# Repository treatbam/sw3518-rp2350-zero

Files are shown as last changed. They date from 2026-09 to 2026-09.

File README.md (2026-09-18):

# sw3518-rp2350-zero

Portable **SW3518** USB charger meter on **Waveshare RP2350-Zero** with a **1.4″ SPI TFT (128×128 ST7735S)**, two momentary buttons, and a small haptic motor.

This is the pocket / field sibling of [sw3518-GEEK](https://github.com/treatbam/sw3518-GEEK). **`env:rp2350-zero` has no Wi‑Fi.** **`env:picow`** (this `picow` branch) is the same TFT meter on a **Raspberry Pi Pico W** with **MQTT Home Assistant discovery**.

MIT licensed.

## Features (MVP)

| Page | Contents |
|---|---|
| **MAIN** | Large total W (text size 3), tight Vin/Vout + C/A row, load-share, compact C/A sparklines |
| **C** | USB-C zoom (large W, V/A, peaks, ~42px sparkline) |
| **A** | USB-A zoom |
| **S** | Compact PEAK/AVG/ENERGY grid, then C/A spark bands |

- Status crumbs along the top (`M C A S`) + live/idle pip (short labels so nothing overflows 128px)
- Square **128×128** layouts packed for the 1.4″ panel; ASCII-only TFT strings
- Session tracking in RAM (charged ms while load present, mWh, peaks) — no NVS required for MVP. I2C loss **pauses** energy (does not bill the outage). Host tests: `make -C tests test`.
- Haptic pulse on protocol change, page enter, session clear, and A-long test
- Night dim: backlight PWM drops after ~90 s idle; any button wakes it
- Onboard **WS2812** (GP16): blink *count* = what’s missing. 0 = OK (dim cyan heartbeat), **1 orange = SW3518 missing**, 2 magenta = TFT missing, 3 red = both. Night dim lowers brightness. TFT has no MISO on this pin map, so 2-blink cannot be proven and is reserved.

### Button grammar

| Button | Short | Long (~800 ms) |
|---|---|---|
| **A** (GP6) | Next page | Haptic test pulse |
| **B** (GP7) | Jump to Session (or prev if already there) | Clear session + haptic |

Optional third **Mode** button is reserved in comments in `include/pins.h` (unused in MVP).

## Default pin map

Soldering helper (Zero front/back + wire-to-part): [`docs/wiring-solder-guide.png`](docs/wiring-solder-guide.png). Regenerate with `python3 docs/make_solder_pinout.py`.

Edit `include/pins.h` (also summarized here).

| Function | GPIO | Notes |
|---|---|---|
| TFT SCK | **2** | SPI0 SCK, **front** edge |
| TFT MOSI | **3** | SPI0 TX, front edge |
| TFT CS | **1** | front edge |
| TFT DC | **15** | front left (GP16 is onboard WS2812) |
| TFT RST | **8** | front edge |
| TFT BL | **14** | PWM night dim, front left |
| WS2812 | **16** | Onboard RGB (Waveshare schematic DIN, `PICO_DEFAULT_WS2812_PIN`) |
| I2C SDA | **4** | Wire / **I2C0** (RP2350 GP4/5) |
| I2C SCL | **5** | SW3518 addr **0x3C** |
| BTN_A | **6** | `INPUT_PULLUP`, active LOW |
| BTN_B | **7** | `INPUT_PULLUP`, active LOW |
| HAPTIC | **9** | Active HIGH → N‑FET gate |

> **I2C naming:** GP4/GP5 are **I2C0** (`Wire`) on RP2350. The “I2C1” label in planning docs meant “the charger I2C bus,” not the hardware I2C1 block (that would be GP6/7 and would collide with the buttons).

## Pico W (`env:picow`)

Same 128×128 UI and SW3518 I2C driver. Wi-Fi publishes GEEK-style **MQTT sensors** with Home Assistant discovery (`homeassistant/sensor/sw3518pw_xxxx/...`). ESPHome would mean rewriting the charger + TFT stack; MQTT on this firmware is the smaller path.

Solder helper: [`docs/wiring-solder-guide-picow.png`](docs/wiring-solder-guide-picow.png) (`python3 docs/make_solder_pinout_picow.py`).

| Function | Pico W GPIO | Notes |
|---|---|---|
| TFT SCK | **18** | SPI0, right rail |
| TFT MOSI | **19** | SPI0 |
| TFT CS | **17** | |
| TFT DC | **none** | 3-wire SPI (`PIN_TFT_DC = -1`). If the FPC says **A0** or **RS**, that is DC — wire it to GP16. |
| TFT RST | **20** | |
| TFT BL | **21** | PWM |
| I2C SDA/SCL | **4 / 5** | SW3518 `0x3C` |
| BTN A/B | **6 / 7** | same grammar |
| Haptic | **9** | |
| Status | **LED_BUILTIN** | CYW43 LED, blink count = SW3518 missing |

```bash
cp include/secrets.h.example include/secrets.h   # fill WIFI_SSID, MQTT_HOST, …
pio run -e picow
```

Empty `WIFI_SSID` still builds (TFT-only). Topics: `picow/sw3518/{vin,vout,i_c,i_a,power,power_c,power_a,protocol,session_wh,session_peak_w,charging,linked,status}`. Do not use GP23–25 (Wi-Fi). Pico BOOT/RUN are flash/reset, not UI.

**ESPHome rewrite** (native HA API, OTA, YAML TFT): `sw3518-picow.yaml` + `components/sw3518/` at the **repo root**. Copy `secrets.yaml.example` → `secrets.yaml`, then `esphome run sw3518-picow.yaml`. Same Pico W pins. Arduino `env:picow` MQTT and ESPHome are alternatives — flash one or the other.

## Display / ST7735 init

Assumes a **1.4″ / 1.44″ 128×128** ST7735S module driven by **Adafruit_ST7735**.

Default init tab (sets 128 height + column/row start — do **not** use the 1.8″ BLACKTAB/GREENTAB here):

```cpp
#define ST7735_INIT_TAB INITR_144GREENTAB
```

If the image is shifted a few pixels, try `INITR_HALLOWING` (also 128×128) in `include/pins.h`. Flip rotation with `1`/`2`/`3` in `initDisplay()` if the panel is mounted rotated.

A full RGB565 canvas (`128×128×2 = 32 KB`) is used; RP2350 SRAM (~520 KB) is fine.

## BOM notes

- **Waveshare RP2350-Zero**
- **SW3518 / SW3518S** charger module with I2C (0x3C)
- **1.4″ SPI ST7735S** 128×128 TFT
- **2×** momentary NO buttons to GND
- **Haptic / coin vibration motor** driven by an **N‑channel MOSFET** (logic-level gate from GP9), **flyback diode** across the motor, motor supply from 3V3 or 5V as appropriate for the motor (do **not** power the motor through the GPIO)

```
GP9 ──[series R ~100Ω optional]── FET gate
FET source ── GND
FET drain ── motor (−)
motor (+) ── 3V3/5V
diode cathode to motor (+), anode to drain
```

## PlatformIO

Uses **earlephilhower Arduino-Pico** via maxgerhardt’s PlatformIO platform:

```ini
[env:rp2350-zero]
platform = https://github.com/maxgerhardt/platform-raspberrypi.git
board = waveshare_rp2350_zero
framework = arduino
board_build.core = earlephilhower
monitor_speed = 115200
```

If `waveshare_rp2350_zero` is missing in your platform package, try the closest Waveshare RP2350 / Pico 2 board id (e.g. `rpipico2`) and keep the same core flag — then update this README.

```bash
cd sw3518-rp2350-zero
pio run
pio run -t upload
pio device monitor -b 115200
```

### Flash via UF2 (no picotool)

1. Hold **BOOT**, tap **RESET** (or plug USB while holding BOOT)
2. RP2350 appears as a USB mass-storage drive
3. Copy `.pio/build/rp2350-zero/firmware.uf2` onto the drive
4. Board reboots into the sketch

CDC serial is enabled (`ARDUINO_USB_CDC_ON_BOOT`) for `Serial` over the Zero’s USB.

## Driver

`include/sw3518.h` + `src/sw3518.cpp` are adapted from the GEEK project:

- Same register / ADC math (including A/C swap at ADC types 3/4)
- `Wire.begin` is portable: ESP32 uses `(sda,scl,hz)`; RP2040/RP2350 uses `setSDA` / `setSCL` + `begin` + `setClock`

## UI notes (128×128)

Layouts in `src/main.cpp` are packed for the square 1.4″ panel (32px shorter than the old 1.8″ 160-tall UI):

- **Status:** short crumbs `M C A S`, live pip on the right
- **Main:** size-3 watts kept; Vin/Vout/C/A + load-share; one-line session footer; C/A sparklines ~28px
- **Port (C/A):** large W, V/A row, peaks on one line, sparkline ~42px
- **Session:** PEAK/AVG/ENERGY grid, then C and A spark bands that finish above y=128
- TFT strings are ASCII-only (no em dashes)

Button grammar is unchanged (see table above).

**Case port layout (v3):** DC barrel exits the **+X end** through a wide flared mouth; stacked USB-A/C exits the **+Y long side**. Zero USB-C stays on the opposite end.

## Your SW3518S module

Matched to the common **DC barrel + stacked USB-A / USB-C** board (I2C pads silk `SDA` / `SCK`):

- Case bay tuned to ~**60 × 22 × 14 mm** with - Silkscreen **`SCK` = I2C SCL** (clock). Wire RP2350 `SCL` (GP5) to the pad labeled SCK, `SDA` (GP4) to SDA, and share GND.
- If your PCB measures different, edit `SW_L` / `SW_W` / `SW_H` in `case/generate_case.py` and re-run it.

## Wokwi simulation

Wokwi has **no official RP2350 board** yet. This repo includes a **Pico (RP2040) sim twin** that reuses the same GPIO numbers and UI firmware:

```bash
pio run -e pico-wokwi
```

Then open `diagram.json` with the [Wokwi VS Code extension](https://docs.wokwi.com/vscode/getting-started) (see `wokwi.toml` + `wokwi/README.md`).

- ST7735 via custom chip `chip-st7735`
- Buttons A/B + haptic LED
- `-DWOKWI_SIM=1` feeds fake SW3518 snapshots (no real I2C charger in the sim)

Flash hardware with `env:rp2350-zero` only — not the Wokwi UF2.

## Pocket case (v5)

v5.1: **no side USB cut and no through-wall bars**. Flash the Zero with the lid off. Earlier “missing corner” / side bars were a Zero USB-C cut and ledges punching through the walls.

Module-specific details:
- **Barrel**: tight ~8 mm body + 10 mm collar recess (5.5×2.1 jack), flush on one end
- **USB**: dual-tier mouth (C below, A above) sized to the stacked connector, flush on the other end
- **4×** mounting bosses for the SW3518 corner holes
- Cap clearance wells for the electrolytics under the deck
- Lid A/B beside the screen; Zero USB-C mid-side for programming

Outer ~**62 × 38 × 25 mm**. Dry-fit and tell me if hole spacing or jack height is off.

## Pocket case (v4 — flush ends)

SW3518S is the **length spine**:
- **DC barrel** flush with one case end
- **Stacked USB-A/C** flush with the opposite end
- 1.8″ TFT + RP2350-Zero on an **upper deck** above the charger
- Zero USB-C exits a **side** opening for flashing

Outer ~**62.4 × 42.0 × 25.6 mm**.

Print `case/pocket_bottom.stl` + `case/pocket_lid.stl`. Pad silk `SCK` = I2C SCL.
**Buttons (v4.2):** on the **lid** beside the screen (A/B), not the long sides. Side wall holes removed. Wire 6×6 tacts under the lid to GP6/GP7.

## Wokwi simulation

Wokwi has **no official RP2350 board** yet. This repo includes a **Pico (RP2040) sim twin** that reuses the same GPIO numbers and UI firmware:

```bash
pio run -e pico-wokwi
```

Then open `diagram.json` with the [Wokwi VS Code extension](https://docs.wokwi.com/vscode/getting-started) (see `wokwi.toml` + `wokwi/README.md`).

- ST7735 via custom chip `chip-st7735`
- Buttons A/B + haptic LED
- `-DWOKWI_SIM=1` feeds fake SW3518 snapshots (no real I2C charger in the sim)

Flash hardware with `env:rp2350-zero` only — not the Wokwi UF2.

## Pocket case

Printable shell under [`case/`](case/):

- Waveshare RP2350-Zero pocket + USB-C access
- 1.8" ST7735 module pocket + lid window (tunable)
- SW3518S dual-port bay (~50x30x12 mm approximate — dry-fit)
- Side 6x6 tact holes, coin haptic pocket, I2C cable channel
- Friction lid + optional M2 bosses

```bash
/workspace/.cadvenv/bin/python case/generate_case.py
```

See [`case/README.md`](case/README.md) and `case/case_meta.json` for outer dims and tunables.

## Layout

```
include/pins.h      pin map + ST7735 tab define
include/sw3518.h    charger driver API
src/sw3518.cpp      charger driver
src/main.cpp        UI, buttons, haptic, session
case/               pocket shell STLs + generator
platformio.ini
```

## License

MIT — see [LICENSE](LICENSE).

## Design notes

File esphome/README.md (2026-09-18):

# ESPHome — SW3518 Pico W

YAML and the `sw3518` component live at the **repo root** (ESPHome requires `components/<name>/` next to the yaml):

- [`../sw3518-picow.yaml`](../sw3518-picow.yaml)
- [`../components/sw3518/`](../components/sw3518/)

Arduino firmware in `src/` is unchanged.

## Why ESPHome here

`env:picow` already publishes MQTT discovery. ESPHome adds OTA, the HA device API, and YAML for the TFT/buttons without a custom MQTT client. The SW3518 I2C protocol is a **local external component** (`components/sw3518`) — same registers as `src/sw3518.cpp`.

## VS Code

Open the **repo root** (the folder with `platformio.ini` and `sw3518-picow.yaml`). The stock ESPHome schema still underlines `sw3518:` — that is normal. Compile anyway.

If you copy yaml into the HA add-on, copy the whole `components/sw3518/` tree next to it.

## Flash

```bash
# repo root (next to platformio.ini)
cp secrets.yaml.example secrets.yaml
esphome run sw3518-picow.yaml
```

First upload: hold **BOOT**, plug USB, then run (UF2). Later updates are OTA.

HA: Settings → Devices → ESPHome → add `sw3518-picow` (encryption key is printed on first boot if you add `api.encryption`).

## Pins

See `docs/wiring-solder-guide-picow.png`. I2C **GP4/GP5** @ `0x3C`. TFT SPI0 **GP18/19/17/20**, BL **GP21**, buttons **GP6/GP7**, haptic **GP9**.

No DC/A0/RS on the glass: ESPHome’s `ili9xxx` cannot drive 3-wire SPI. Use Arduino `pio run -e picow` (`PIN_TFT_DC = -1`). If the pin is labeled **A0** or **RS**, that *is* DC — GP16.

## UI

- **A short** — Main ↔ Session
- **B short** — Session
- **B hold** — reset session Wh integrator + haptic

Display is RGB565 16-bit (same as the RP2350 Arduino canvas). If the Pico W OOMs or the compile fails, add `color_palette: 8BIT` back under `display:`. If the image is shifted a few pixels, add `dimensions.offset_width` / `offset_height` (1.44″ ST7735 tabs vary).

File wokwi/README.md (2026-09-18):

# Wokwi simulation (portable UI)

Official Wokwi **does not support RP2350 / Pico 2** yet (`wokwi-pi-pico` is RP2040 only).
This folder is a **sim twin**: Raspberry Pi Pico + the same GP map as `include/pins.h`,
with `-DWOKWI_SIM=1` so SW3518 readings are canned (no I2C charger chip in the diagram).

## Parts
- Pico (stand-in for RP2350-Zero)
- ST7735 128×160 (`chip-st7735` custom chip)
- Buttons A/B on GP6/GP7
- LED on GP9 = haptic stand-in

## Run
```bash
pio run -e pico-wokwi
```
Open the repo in VS Code with the **Wokwi** extension, open `diagram.json`, start sim.

Or from repo root (after build):
```bash
# firmware paths are in ../wokwi.toml
```

Hardware flash still uses `env:rp2350-zero` — do **not** flash the `pico-wokwi` UF2 to a real Zero.

## Display wiring notes
The `chip-st7735` pins are **SCK / MOSI / CS / DC / RST** (not SCL/SDA).
**DC is GP15** on both Wokwi and hardware. GP16 is the Zero’s onboard WS2812 (Pico sim: unused / SPI0 MISO).

## Still blank?

1. **Build before simulate** (Wokwi needs the UF2 on disk):
   ```bash
   pio run -e pico-wokwi
   ls .pio/build/pico-wokwi/firmware.uf2
   ```
2. Pull latest `diagram.json` — ST7735 pins are **SCK/MOSI/DC/RST** (DC = **GP15** in sim).
3. Open the **Wokwi** output / serial panel — you should see `ST7735 Driver Chip Initialized` and `sw3518-rp2350-zero`.
4. On boot the sim flashes **red then green** briefly (soft-SPI prove-alive). If you never see that, the firmware isn’t loading or SPI isn’t reaching the chip.
5. Hardware Zero uses HW SPI, DC=GP15, WS2812 on GP16. Don’t flash `pico-wokwi` UF2 to a real RP2350-Zero.

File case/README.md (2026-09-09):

# Pocket case (RP2350-Zero + 1.8" TFT + SW3518S)

Parametric printable shell for the portable meter. **No light pipes, no button rods/caps.**

## Print

| File | Notes |
|---|---|
| `pocket_bottom.stl` | Main shell with Zero / TFT / SW3518 bays |
| `pocket_lid.stl` | Lid with screen window + friction lip (print outer face down) |
| `pocket_preview_exploded.stl` | Visual only |

Regenerate:

```bash
/workspace/.cadvenv/bin/python case/generate_case.py
```

## Outer size

See `case_meta.json` -> `print_outer_mm` (generated). Typical ~**118 x 40 x 18 mm** with default tunables.

## Stock assumptions (dry-fit!)

| Part | Default (mm) | Notes |
|---|---|---|
| Waveshare RP2350-Zero PCB | 23.5 x 18 x 1 | USB-C on short edge; access hole in -X wall |
| 1.8" ST7735 module outer | **34.0 x 55.0 x 3.6** | Common class; length varies ~47.5-58 -- tune `TFT_OUTER_*` |
| Screen window | **28 x 35** active-ish | Tune `TFT_WIN_*` / `TFT_WIN_OFF_X` |
| SW3518S dual-port bay | **50 x 30 x 12** | **Approximate** -- dry-fit and retune `SW_L/W/H` |
| Coin haptic | O10.2 x 2.8 deep | Under/near Zero |
| Buttons | O6.4 side holes | 6x6 tact, finger-direct (no rods) |

## Features

- Rounded corners
- USB-C access for the Zero
- TFT pocket + lid window / shallow bezel
- SW3518 rectangular bay with +X port face clearance
- I2C cable channel between Zero and SW3518
- Side tact holes (A/B)
- Haptic pocket + board rails
- Friction lip lid + 2x M2 screw bosses

## Print settings

PLA for fit check, PETG for daily · 0.2 mm · 3 walls · 15-20% · supports usually off

Tune `GAP`, `TFT_OUTER_*`, `TFT_WIN_*`, `SW_*`, `HAP_D` in `generate_case.py` after a dry-fit.

### SW3518S (user module)

Barrel-jack + stacked USB-A/C. Bay ~60×22×14 mm; USB out +X; barrel on +X end, USB on +Y side. Pad `SCK` is I2C SCL.

**Case port layout (v3):** DC barrel exits the **+X end** through a wide flared mouth; stacked USB-A/C exits the **+Y long side**. Zero USB-C stays on the opposite end.

## Pocket case (v5)

v5.1: **no side USB cut and no through-wall bars**. Flash the Zero with the lid off. Earlier “missing corner” / side bars were a Zero USB-C cut and ledges punching through the walls.

Module-specific details:
- **Barrel**: tight ~8 mm body + 10 mm collar recess (5.5×2.1 jack), flush on one end
- **USB**: dual-tier mouth (C below, A above) sized to the stacked connector, flush on the other end
- **4×** mounting bosses for the SW3518 corner holes
- Cap clearance wells for the electrolytics under the deck
- Lid A/B beside the screen; Zero USB-C mid-side for programming

Outer ~**62 × 38 × 25 mm**. Dry-fit and tell me if hole spacing or jack height is off.

## Pocket case (v4 — flush ends)

SW3518S is the **length spine**:
- **DC barrel** flush with one case end
- **Stacked USB-A/C** flush with the opposite end
- 1.8″ TFT + RP2350-Zero on an **upper deck** above the charger
- Zero USB-C exits a **side** opening for flashing

Outer ~**62.4 × 42.0 × 25.6 mm**.

Print `case/pocket_bottom.stl` + `case/pocket_lid.stl`. Pad silk `SCK` = I2C SCL.
**Buttons (v4.2):** on the **lid** beside the screen (A/B), not the long sides. Side wall holes removed. Wire 6×6 tacts under the lid to GP6/GP7.

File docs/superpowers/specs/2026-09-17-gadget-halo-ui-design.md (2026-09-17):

# Gadget halo UI — SW3518 RP2350-Zero

Date: 2026-09-17  
Status: draft for user review  
Device: Waveshare RP2350-Zero, 1.4″ 128×128 ST7735S, two lid buttons, haptic, no Wi-Fi.

## Goal

Make the pocket meter feel like a charger-brick gadget (Anker/Ugreen), not a cramped four-page scope. Watts stay honest. Motion is in the ring, color, and haptic. This brick never has both USB-C and USB-A loaded at once.

## Personality

Bright halo around a large watt number. Green → yellow → hot orange as load climbs. Protocol flash stays a yellow chip. ASCII-only 5×7 GFX text. Full RGB565 canvas 128×128 (32 KB).

## Non-goals

- Wi-Fi, MQTT, BLE, web (GEEK)
- True efficiency (no input current)
- Settings page / power-ceiling picker
- USB-C and USB-A zoom pages
- C/A load-share bar (two-port lie)
- Auto-jump between port pages
- Arcade boot videos, page-slide chrome, particle FX
- Case CAD changes

## Pages (three)

Header crumbs: `CHG  M  S  T` plus live pip (or unlink icon if I2C down). No C/A crumbs.

| Crumb | Page | Job |
|---|---|-----|
| **M** | Main | Halo + watts + live port |
| **S** | Session | PEAK / AVG / Wh / duration / Vpk |
| **T** | Timeline | Filled watts-vs-time for this session |

A-short cycles M → S → T → M. Page enum order is `Main, Session, Timeline` so B-short from Session goes to **Main** (previous), not Timeline.

### Main

- Status bar as above.
- Halo ring, 100 W = full circle. If live watts or session peak exceed 100 W, full-scale becomes `max(100, peakW)` for the rest of the session (does not shrink until clear).
- Center: eased `xx.xW`.
- LIVE/IDLE, protocol name (yellow invert flash 2 s on change), port badge `C` or `A` or `--`.
- One V/A line for the **active** port only (current > 50 mA). If neither, show Vin / Vout.
- Footer: `12m  1.23Wh  pk65` when session has data; else a short hint `A:page B:ses holdB:clr`.
- Unlinked: orange `CHG` + chip icon; ring empty; pages still work.

Port badge: `C` if `ic_ma` is the larger load, `A` if `ia_ma` is larger, `--` if idle. Never draw both amps on Main.

### Session

Keep the compact PEAK / AVG / Wh grid, Vpk, duration. Drop the two spark bands (those live on T). Use the bright palette (cyan labels, hot orange Wh).

### Timeline

One series: total watts vs session time, filled area, yellow/orange stroke, dashed vertical at peak sample. Caption: duration, `pk`, live port + protocol. Empty state: `no session`. History buffer remains the existing session hist (store **total W**, not dual C/A traces). Rebin/downsample behavior stays.

## Motion

- I2C snapshot ~200 ms (unchanged).
- Face redraw ~50 ms (≈20 Hz). Display watts and ring angle **ease** toward the latest snapshot (exponential, time-constant ~120 ms). Protocol text, port badge, and LIVE/IDLE snap on the sample.
- Color of the ring (and watt glow) from load fraction of current full-scale: low green, mid yellow, high hot orange. Bright (high saturation), not the old dim 0x07E0-on-black.
- Peak-hold: when a new session peak lands, show `pk HOLD` ~1.5 s and a tick on the ring. Haptic tick.
- Night dim: 90 s after last **button** or **plug** (load 0→1). Buttons or plug restore full backlight. Charging alone does not prevent dim.

## Haptic

| Event | Pulse |
|---|---|
| Plug (load appears) | Single punch ~40 ms |
| Unplug (after 1.5 s debounce) | Down-slide ~80 ms softer |
| Protocol change | Double-tap |
| New peak | Short tick |
| Page change | Existing light pulse |
| Clear session | Existing longer pulse |
| A-long | Wake backlight; light pulse (not a settings menu) |

No haptic when I2C is lost (avoid alarm spam).

## Buttons

Hardware stays two lid buttons.

| | Short | Long (~800 ms) |
|---|---|---|
| **A** | Next page M/S/T | Wake backlight + pulse |
| **B** | Jump Session; if already Session, previous page | Clear session in RAM **and** flash; haptic; go Main |

Glance path: no press required. Watts and ring run themselves.

## Persistence

Always on. No toggle.

- **Save:** session scalars only — `chargedMs`, `mwh`, `peakW`, `peakA`, `peakVoutMv`, port peak structs, `startMs` identity as needed, phase as Idle/Paused after restore. **Do not** persist the timeline sample buffer (T starts empty after reboot; S still shows totals).
- **When:** on unplug debounce (session becomes Idle with data), every 10 s while Running, and on clear (write empty record).
- **Where:** flash-backed EEPROM blob (Arduino-Pico EEPROM, versioned packed struct, magic + version). Fits in well under 4 KB without LittleFS.
- **Boot:** if magic/version match and there is data, `adoptPersisted()` so the clock does not bill the off-time.
- **Clear:** B-long wipes RAM and the blob.

Host tests: persist round-trip, adopt-does-not-integrate-gap, clear-wipes-blob (blob encode/decode in a portable helper, no Arduino in the test).

## Data / session

Existing `Session` + `Link`/`Phase` stay canonical. Changes:

- History is **one** `histW[]` (total watts), not `histC`/`histA`. Downsample unchanged.
- `onTick` unchanged in spirit (pause on `Link::Lost`, unplug debounce, no gap billing).
- UI must not integrate energy; only Session does.

## Architecture (firmware)

Do not dump this into a 1k-line `main.cpp`. Split:

| Unit | Owns |
|---|---|
| `sw3518` | I2C snapshot (exists) |
| `session` | energy, peaks, histW, persist encode/decode (exists; extend) |
| `ui` | halo, easing, pages M/S/T, palette, crumbs |
| `main` | pins, buttons, haptic, backlight, 50 ms / 200 ms ticks |

`ui` draws from: latest snapshot, eased display watts, Session, charger present, millis.

Interpolator lives in `ui` (not Session). Tests cover Session + persist only.

## Loop

```
50 ms:  haptic; buttons; ease toward last snap; drawFrame
200 ms: readSnapshot or probe; Session.onTick; maybe persist; protocol/peak/plug haptic edges
```

If snapshot fails: `Link::Lost`, clear live snap, pause session, unlink icon.

## Testing

- Keep `make -C tests test`.
- Add persist blob round-trip and “restore does not add off-time energy.”
- Add histW downsample still halves count / doubles period.
- No hardware-in-loop required for this spec.

## Risks

- ST7735 brightness is panel-limited; “brighter” is palette (not PWM-to-11). Backlight PWM stays 255 when awake.
- 20 Hz full-canvas blit is fine on RP2350 (32 KB SPI). If it stutters, drop to 15 Hz, keep easing.
- EEPROM wear: 10 s writes while charging are acceptable for hobby flash; only write if `dirty`.

## Locked decisions

1. Halo Main, filled Timeline, numbers Session.
2. Drop C/A pages, crumbs, and share bar.
3. Brighter gadget palette; 100 W halo, grows if exceeded.
4. Ease ring + watts; full haptic language above.
5. Keep A/B; no settings page.
6. Persist stats always; not the spark buffer.
7. Case files untouched.

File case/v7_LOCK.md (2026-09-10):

# v7 caliper lock (STEP rebuild)

**Master:** `case/v7_lock.json` — freeze date 2026-09-09.  
**Do not** import `v62_*.stl` as the CAD master (reference only).

## Parts
base · mid · lid · tft_tray · optional TPU button pad · optional Zero retainer clip

## Hard numbers
| Item | mm |
|---|-----|
| SW3518 PCB | 57 × 22 × 1.6 |
| Cap bores | Ø7.25 × 18 deep (2×) |
| Inductor pocket | 12.9² (part 12.5² × 9 H) |
| Heatsink pocket | 7.4² (keepout 7³) |
| Barrel body | 13 × 11 × 11; +4 past PCB; +X |
| USB stack | +2 past PCB; −X; C under A |
| Zero | 23.5 × 18; no screw holes; snug pocket + USB detent |
| TFT outer | 55 × 34 × 3.6; window 35 × 28 |
| Button holes | Ø4.2 aligned pair beside bezel |
| PETG pocket clear | ~0.25 / side |
| Wall / gap | 1.6 / 0.40 |

## Print gate
1. Base only → dry-fit SW3518 glove  
2. Mid → Zero pocket + ports  
3. Lid + tray  

@Code Troubleshooter: amend pinout/clearance notes here if anything’s off.  
@Creative CAD Master: sketch from this lock only → `case/v7_step/` (STEP + STL per part).

## Wiring / clearance (CT amend)
| Bus | Pins | Notes |
|-----|---|---|
| I2C SW3518 | GP4 SDA, GP5 SCL (`0x3C`) | Silk `SCK` = SCL; exit +Y |
| TFT SPI | 18/19/17/16/20/21 | 6-wire bundle Zero → lid tray |
| Buttons | GP6 A, GP7 B | Active LOW pullup |
| Haptic | GP9 | N-FET; optional well |

Flex channel ≥ **10 × 3 mm** on +Y; **~25 mm** slack so lid lifts off without yanking joints.
Do not invade the 57×22 PCB envelope except glove wells + port tunnels.

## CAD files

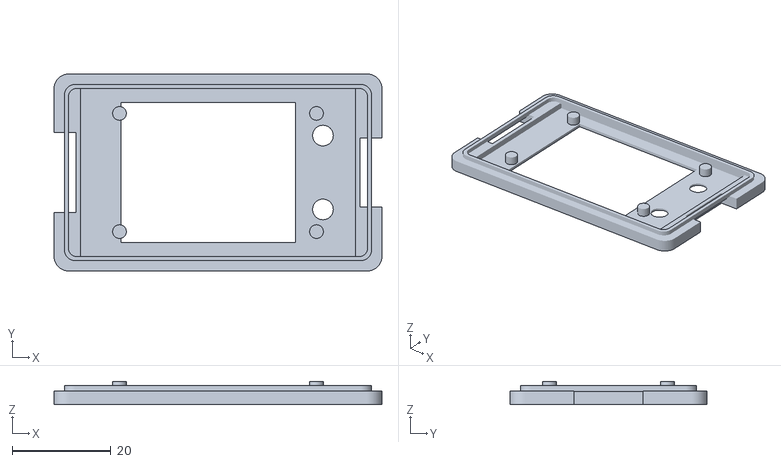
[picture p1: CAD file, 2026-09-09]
case/v6_lid.stl
66.6 x 40.0 x 4.70

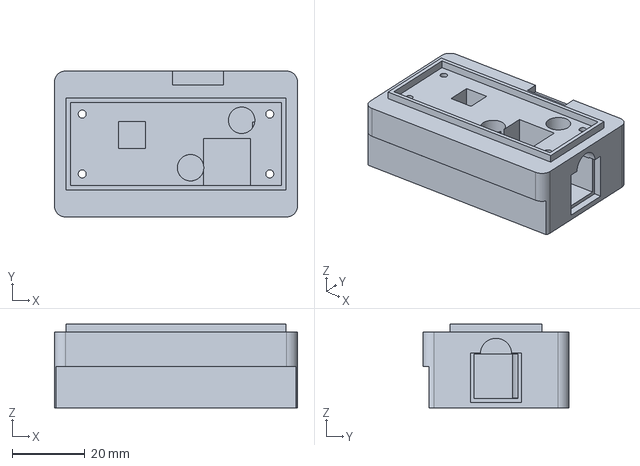
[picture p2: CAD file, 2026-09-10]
case/v7_step/v7_base.step
66.6 x 40.0 x 23.0 mm

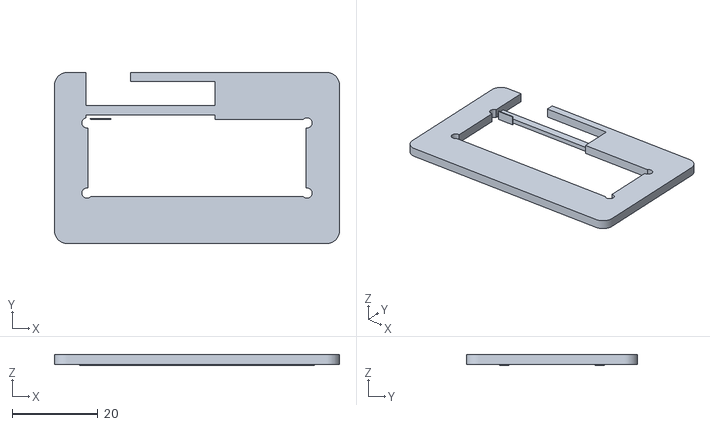
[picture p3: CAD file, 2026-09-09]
case/v6_mid_plate.stl
66.6 x 40.0 x 2.60

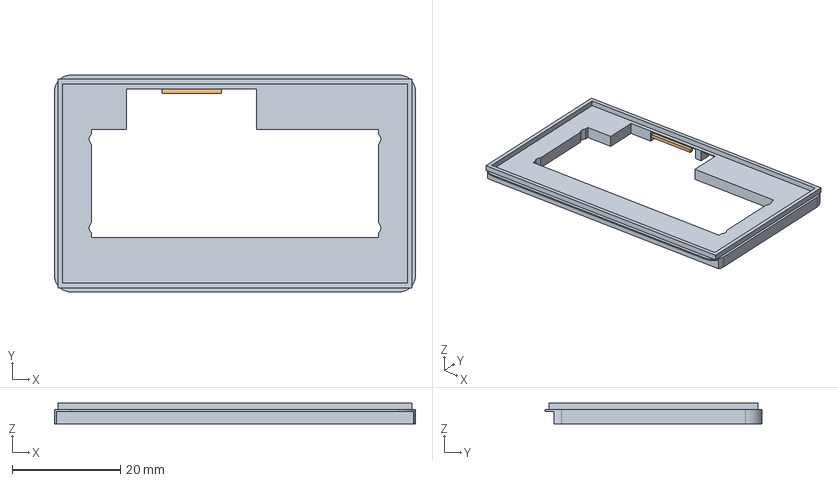
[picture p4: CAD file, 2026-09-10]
case/v7_step/v7_mid.step
66.6 x 40.0 x 3.80 mm

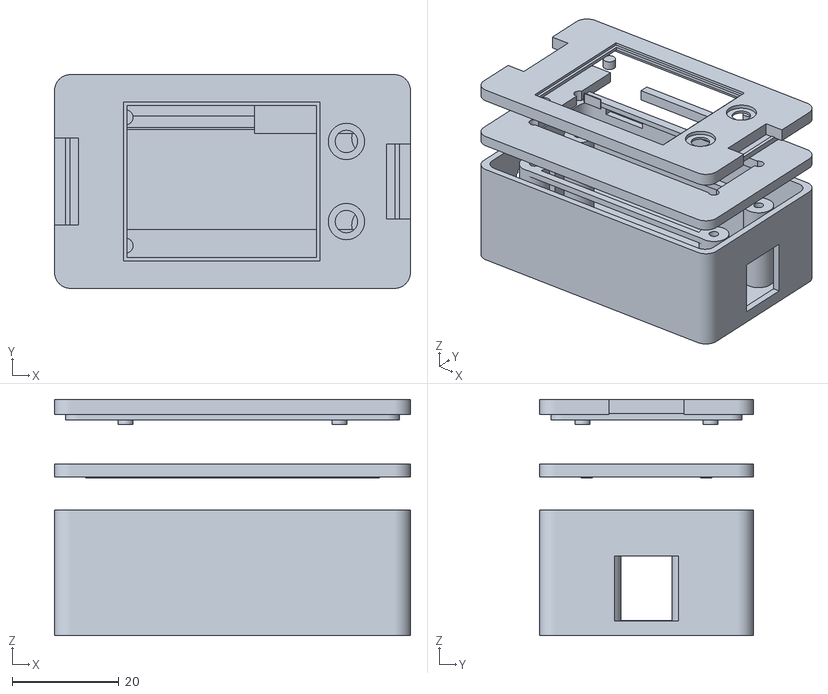
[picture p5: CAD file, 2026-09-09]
case/v6_preview_exploded.stl
66.6 x 40.0 x 44.2

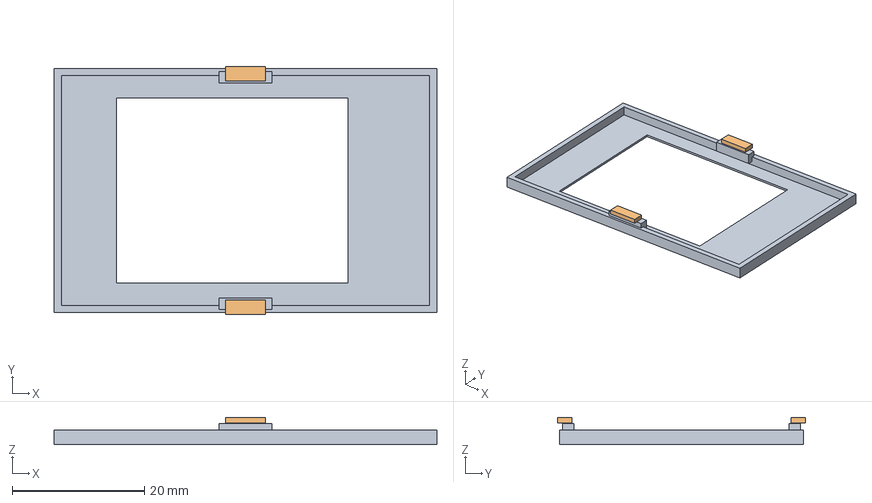
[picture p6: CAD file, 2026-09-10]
case/v7_step/v7_tft_tray.step
58.0 x 37.5 x 4.12 mm

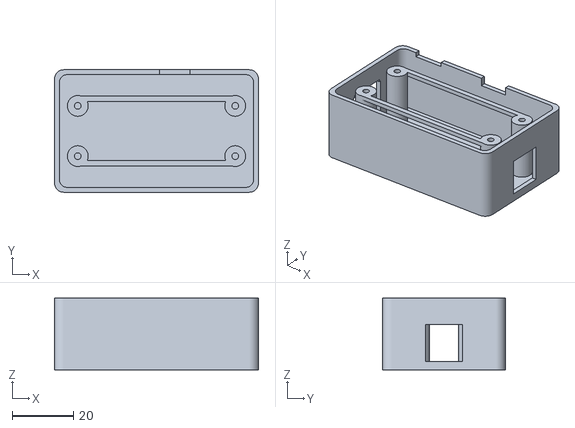
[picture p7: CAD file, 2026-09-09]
case/v6_base.stl
66.6 x 40.0 x 23.5

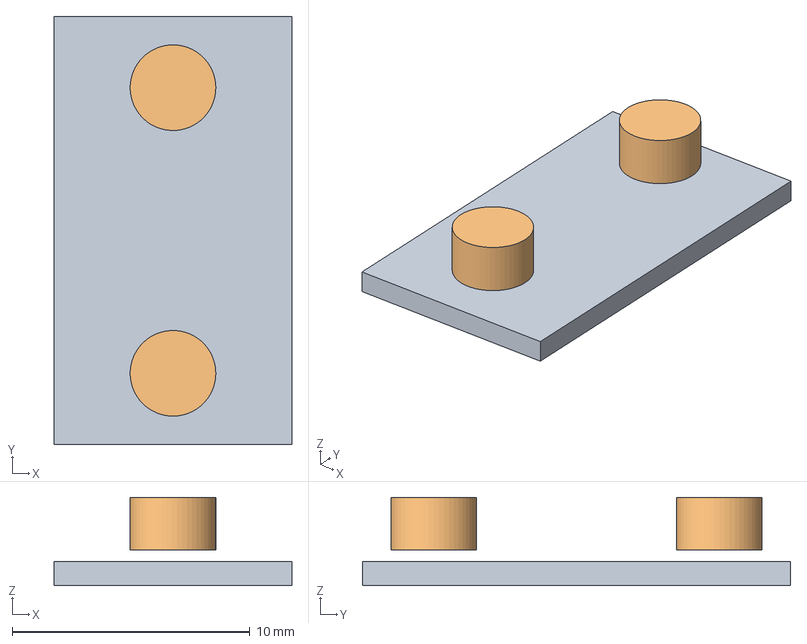
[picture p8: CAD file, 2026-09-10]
case/v7_step/v7_tpu_button_pad.step
10.0 x 18.0 x 3.70 mm

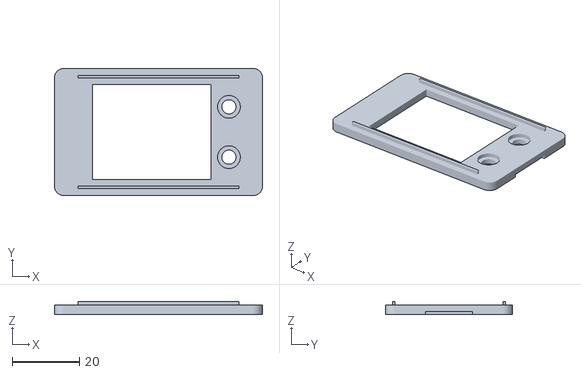
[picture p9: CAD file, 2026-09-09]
case/pocket_lid.stl
62.0 x 37.9 x 3.85

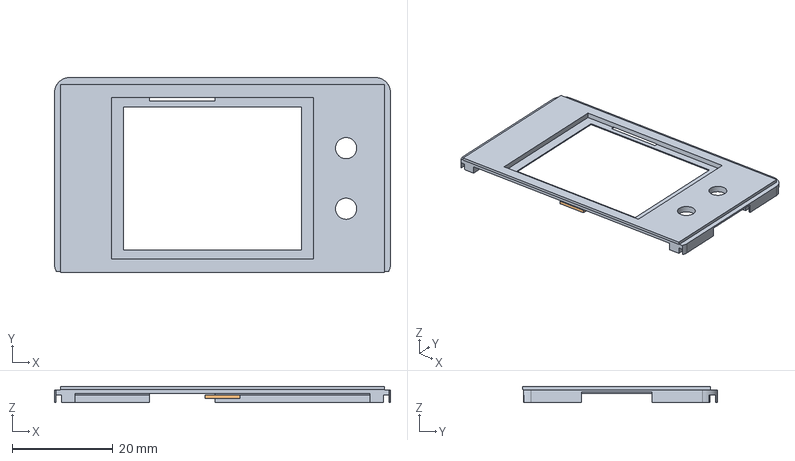
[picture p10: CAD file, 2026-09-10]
case/v7_step/v7_lid.step
66.6 x 38.6 x 3.20 mm

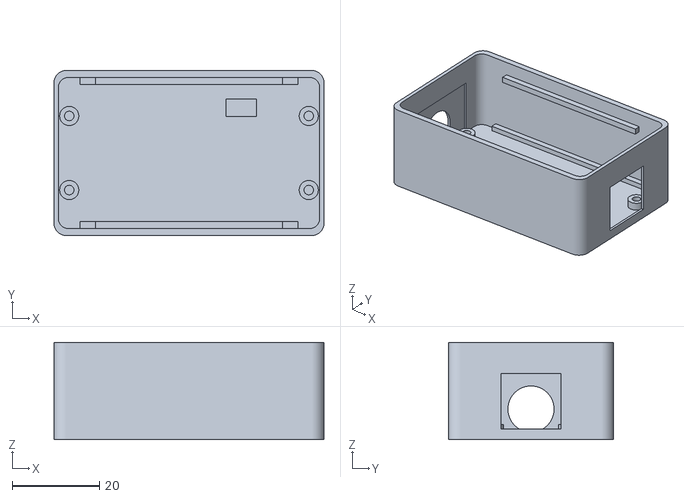
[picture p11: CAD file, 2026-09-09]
case/pocket_bottom.stl
62.0 x 37.9 x 22.3

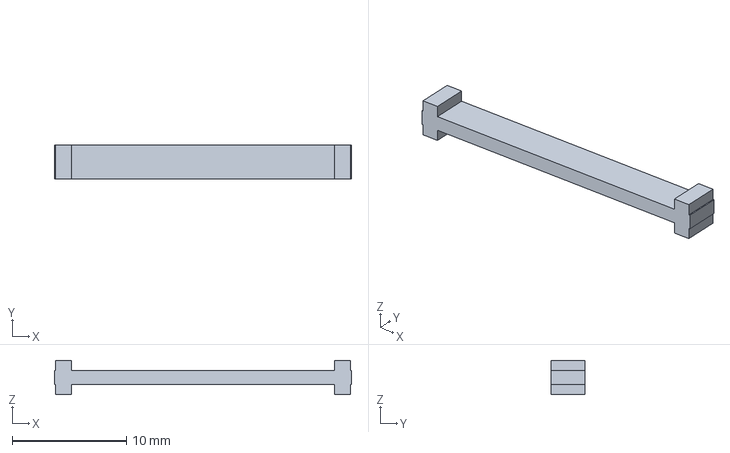
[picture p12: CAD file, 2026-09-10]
case/v7_step/v7_zero_retainer_clip.step
26.0 x 3.00 x 3.00 mm

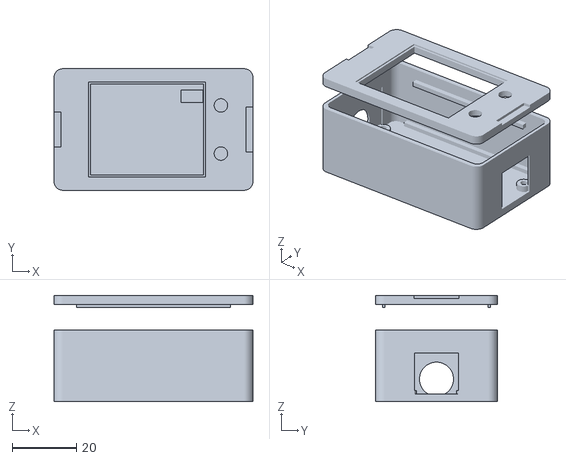
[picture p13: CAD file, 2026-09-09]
case/pocket_preview_exploded.stl
62.0 x 37.9 x 33.1

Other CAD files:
case/v7_step/v7_base.stl
case/v7_step/v7_lid.stl
case/v7_step/v7_mid.stl
case/v7_step/v7_tft_tray.stl
case/v7_step/v7_tpu_button_pad.stl
case/v7_step/v7_zero_retainer_clip.stl

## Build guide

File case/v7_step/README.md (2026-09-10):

# v7 STEP rebuild

Built from `../v7_lock.json` only (no v62 STL master).

## Regen
```bash
/workspace/.cadvenv/bin/python case/generate_v7_step.py
```

## Print gate
1. `v7_base.stl` — SW3518 glove dry-fit
2. `v7_mid.stl` — Zero pocket + USB detent
3. `v7_lid.stl` + `v7_tft_tray.stl`
4. Optional: `v7_tpu_button_pad.stl`, `v7_zero_retainer_clip.stl`

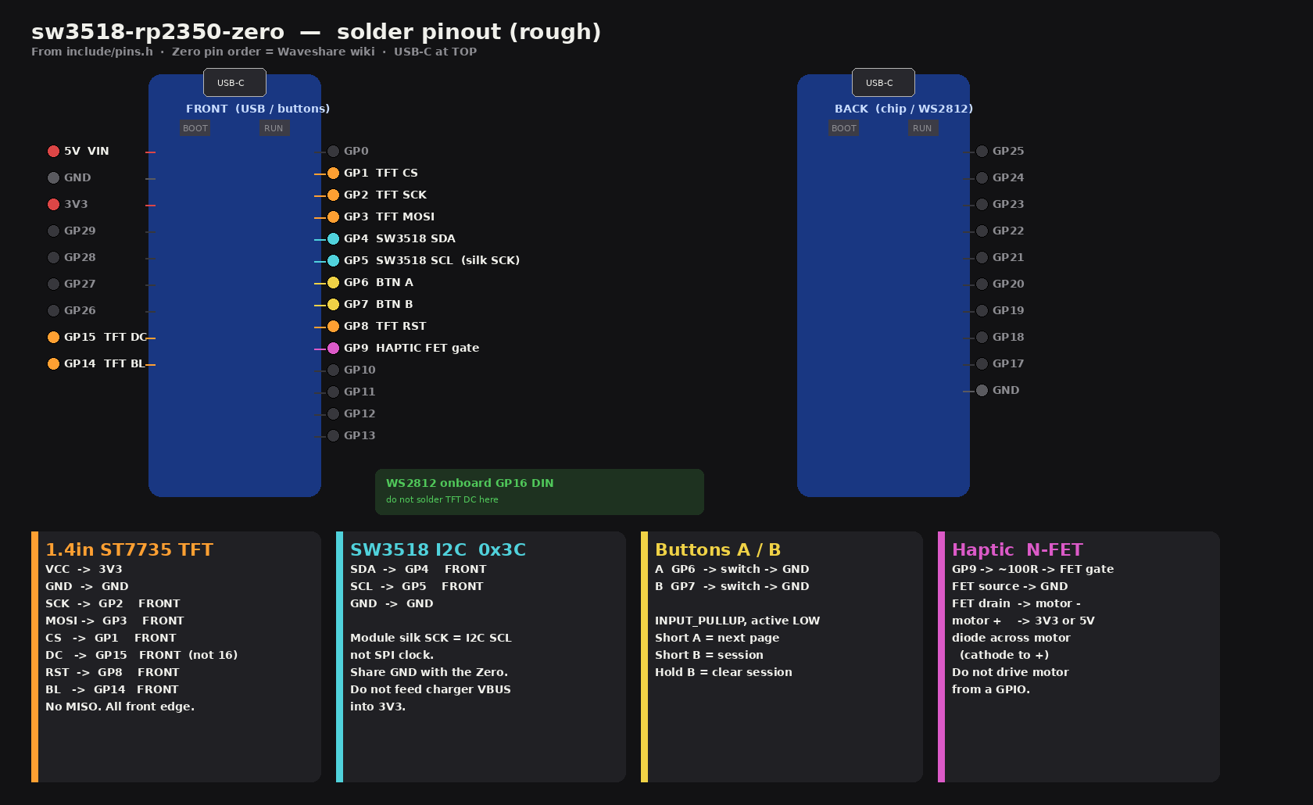
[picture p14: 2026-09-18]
docs/wiring-solder-guide.png

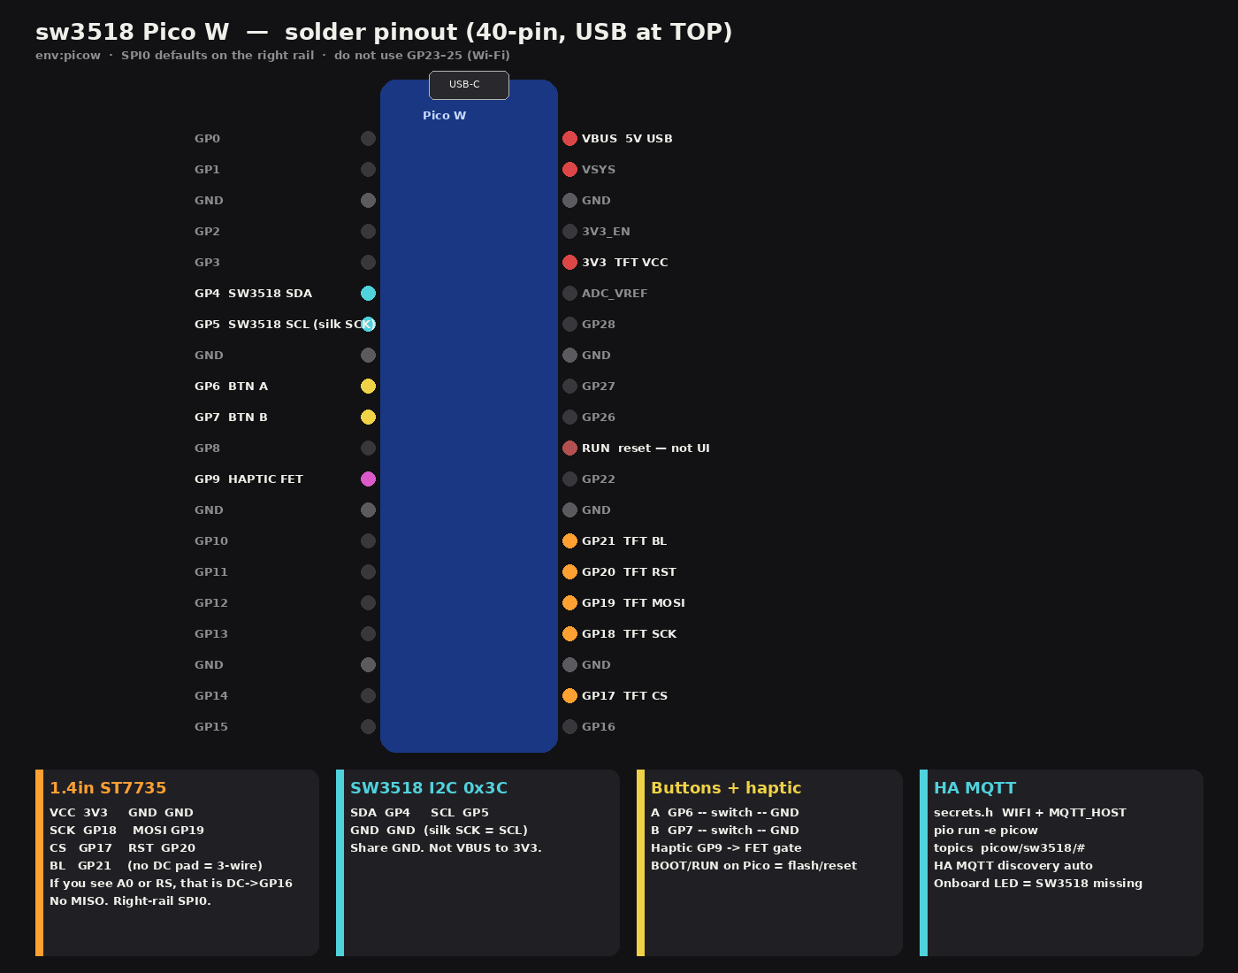
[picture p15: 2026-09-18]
docs/wiring-solder-guide-picow.png

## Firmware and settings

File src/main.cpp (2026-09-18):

#include <Arduino.h>
#include <SPI.h>
#include <Wire.h>
#include <math.h>
#include <string.h>
#include <Adafruit_GFX.h>
#include <Adafruit_ST7735.h>

#include "pins.h"
#include "session.h"
#include "status_led.h"
#include "sw3518.h"
#include "net.h"

// --- colors (RGB565) ---
static constexpr uint16_t COL_BLACK = 0x0000;
static constexpr uint16_t COL_WHITE = 0xFFFF;
static constexpr uint16_t COL_GREEN = 0x07E0;
static constexpr uint16_t COL_CYAN = 0x07FF;
static constexpr uint16_t COL_YELLOW = 0xFFE0;
static constexpr uint16_t COL_MAGENTA = 0xF81F;
static constexpr uint16_t COL_ORANGE = 0xFD20;
static constexpr uint16_t COL_DARKGREY = 0x7BEF;
static constexpr uint16_t COL_LIGHTGREY = 0xC618;
static constexpr uint16_t COL_DIM = 0x4208;

static constexpr int kW = 128;
static constexpr int kH = 128;
static constexpr int kStatusBarH = 12;

// 128-tall pack (size-3 watts kept; sparks and session footer give up the 32px).
static constexpr int kYHdr = 14;
static constexpr int kYWatts = 24;       // size 3 → 24..47
static constexpr int kYMainVin = 50;
static constexpr int kYMainAmps = 60;
static constexpr int kYShareBar = 78;    // label at y-10
static constexpr int kYMainSes = 86;
static constexpr int kYMainSpark = 96;
static constexpr int kMainSparkH = 28;   // 96..124
static constexpr int kYPortVA = 50;
static constexpr int kYPortPk = 62;
static constexpr int kYPortChg = 72;
static constexpr int kYPortSpark = 82;
static constexpr int kPortSparkH = 42;   // 82..124
static constexpr int kYSesGrid = 26;
static constexpr int kYSesVals = 38;
static constexpr int kYSesVpk = 56;
static constexpr int kYSesCLbl = 66;
static constexpr int kYSesCSpark = 76;
static constexpr int kSesSparkH = 18;
static constexpr int kYSesALbl = 98;
static constexpr int kYSesASpark = 108;
static constexpr uint32_t kUiMs = 200;
#if defined(WOKWI_SIM) && WOKWI_SIM
static constexpr uint32_t kUiMsEffective = 500;  // soft SPI is slow
#else
static constexpr uint32_t kUiMsEffective = kUiMs;
#endif
static constexpr uint32_t kNightIdleMs = 90000;
static constexpr int kBlFull = 255;
static constexpr int kBlDim = 64;
static constexpr uint32_t kLongPressMs = 800;
static constexpr uint32_t kDebounceMs = 30;

enum class Page : uint8_t { Main = 0, UsbC = 1, UsbA = 2, Session = 3, Count = 4 };

#if defined(WOKWI_SIM) && WOKWI_SIM
// Soft SPI — Wokwi custom ST7735 chip is more reliable than HW SPI on Pico sim.
Adafruit_ST7735 tft(PIN_TFT_CS, PIN_TFT_DC, PIN_TFT_MOSI, PIN_TFT_SCK, PIN_TFT_RST);
// Draw UI straight to the panel (full-frame RGB bitmap over soft SPI is too slow).
Adafruit_ST7735& canvas = tft;
#else
Adafruit_ST7735 tft(PIN_TFT_CS, PIN_TFT_DC, PIN_TFT_RST);
GFXcanvas16 canvas(kW, kH);
#endif

SW3518 charger;

Page page = Page::Main;
SW3518::Snapshot snap;
SW3518::Protocol lastProtocol = SW3518::Protocol::None;
uint32_t protoFlashUntil = 0;
uint32_t lastUiMs = 0;
uint32_t lastActivityMs = 0;
uint32_t lastHistPushMs = 0;
bool nightDim = false;
int blLevel = kBlFull;
Session session;

// --- haptic (non-blocking PWM burst) ---
static uint32_t hapticUntil = 0;
static uint8_t hapticDuty = 0;

static void hapticPulse(uint16_t ms = 45, uint8_t duty = 200) {
  hapticDuty = duty;
  hapticUntil = millis() + ms;
  analogWrite(PIN_HAPTIC, duty);
}

static void hapticService() {
  if (hapticUntil && (int32_t)(millis() - hapticUntil) >= 0) {
    analogWrite(PIN_HAPTIC, 0);
    hapticUntil = 0;
    hapticDuty = 0;
  }
}

static void setBacklight(int level) {
  if (level < 0) level = 0;
  if (level > 255) level = 255;
  blLevel = level;
  analogWrite(PIN_TFT_BL, level);
}

static void touchActivity() {
  lastActivityMs = millis();
  if (nightDim) {
    nightDim = false;
    setBacklight(kBlFull);
  }
}

static void gfxText(Adafruit_GFX& g, int16_t x, int16_t y, const char* s, uint16_t fg,
                    uint16_t bg, uint8_t size, bool centerX = false, bool right = false) {
  g.setTextSize(size);
  g.setTextColor(fg, bg);
  g.setTextWrap(false);
  const int16_t tw = (int16_t)(strlen(s) * 6 * size);
  if (centerX) x = x - tw / 2;
  else if (right) x = x - tw;
  g.setCursor(x, y);
  g.print(s);
}



static void formatDuration(uint32_t ms, char* out, size_t n) {
  const uint32_t s = ms / 1000, m = s / 60, h = m / 60;
  if (h > 0)
    snprintf(out, n, "%luh%02lum", (unsigned long)h, (unsigned long)(m % 60));
  else if (m > 0)
    snprintf(out, n, "%lum%02lus", (unsigned long)m, (unsigned long)(s % 60));
  else
    snprintf(out, n, "%lus", (unsigned long)s);
}

static void clearSession() {
  session.clear();
  hapticPulse(80, 220);
}

static void drawSparkline(Adafruit_GFX& g, int x, int y, int w, int h, const float* data,
                          uint16_t color, size_t count) {
  g.drawRect(x, y, w, h, COL_DARKGREY);
  if (count < 2 || w < 4 || h < 4) return;
  float mx = 0.1f;
  for (size_t i = 0; i < count; i++) {
    if (data[i] > mx) mx = data[i];
  }
  int prevX = x + 1, prevY = y + h - 2;
  const size_t denom = count > 1 ? count - 1 : 1;
  for (size_t i = 0; i < count; i++) {
    const int px = x + 1 + (int)((w - 3) * i / denom);
    const int py = y + h - 2 - (int)((h - 4) * (data[i] / mx));
    if (i > 0) g.drawLine(prevX, prevY, px, py, color);
    prevX = px;
    prevY = py;
  }
}

// Small chip + slash: SW3518 not on I2C (overlay; pages stay normal)
static void drawUnlinkedIcon(int x, int y) {
  // IC body
  canvas.drawRect(x, y, 10, 8, COL_ORANGE);
  canvas.fillRect(x + 1, y + 1, 8, 6, COL_BLACK);
  // pin stubs
  canvas.drawFastVLine(x + 2, y - 1, 2, COL_ORANGE);
  canvas.drawFastVLine(x + 5, y - 1, 2, COL_ORANGE);
  canvas.drawFastVLine(x + 8, y - 1, 2, COL_ORANGE);
  canvas.drawFastVLine(x + 2, y + 7, 2, COL_ORANGE);
  canvas.drawFastVLine(x + 5, y + 7, 2, COL_ORANGE);
  canvas.drawFastVLine(x + 8, y + 7, 2, COL_ORANGE);
  // slash
  canvas.drawLine(x, y + 7, x + 9, y, COL_ORANGE);
  canvas.drawLine(x, y + 8, x + 9, y + 1, COL_ORANGE);
}

static void clearSnapshot() {
  snap = SW3518::Snapshot{};
  lastProtocol = SW3518::Protocol::None;
}

static void drawStatusBar() {
  canvas.fillRect(0, 0, kW, kStatusBarH, COL_BLACK);
  canvas.drawFastHLine(0, kStatusBarH - 1, kW, COL_DIM);

  gfxText(canvas, 2, 2, "CHG", COL_CYAN, COL_BLACK, 1);

  // Short crumbs so the live pip never overflows on 128px
  const char* crumbs[] = {"M", "C", "A", "S"};
  int active = (int)page;
  if (active < 0) active = 0;
  if (active > 3) active = 3;

  int x = 28;
  for (int i = 0; i < 4; i++) {
    const bool on = (i == active);
    gfxText(canvas, x, 2, crumbs[i], on ? COL_WHITE : COL_DARKGREY, COL_BLACK, 1);
    const int tw = (int)strlen(crumbs[i]) * 6;
    if (on) canvas.drawFastHLine(x, 10, tw, COL_CYAN);
    x += tw + 8;
  }

  if (!charger.present()) {
    // CHG label already drawn; retint + unlink chip icon (top-right)
    gfxText(canvas, 2, 2, "CHG", COL_ORANGE, COL_BLACK, 1);
    drawUnlinkedIcon(kW - 14, 2);
  } else {
    const bool live = snap.ia_ma > Session::kLoadMa || snap.ic_ma > Session::kLoadMa;
    canvas.fillCircle(kW - 6, 5, 3, live ? COL_GREEN : COL_DIM);
  }
}

static void drawLoadShareBar(int y) {
  const float pc = snap.power_c_w;
  const float pa = snap.power_a_w;
  const float tot = pc + pa;
  const int w = kW - 8;
  canvas.drawRect(4, y, w, 6, COL_DARKGREY);
  if (tot < 0.05f) {
    gfxText(canvas, 4, y - 10, "C/A share --", COL_DARKGREY, COL_BLACK, 1);
    return;
  }
  int wc = (int)(w * (pc / tot) + 0.5f);
  if (wc < 0) wc = 0;
  if (wc > w) wc = w;
  if (wc > 0) canvas.fillRect(4, y, wc, 6, COL_YELLOW);
  if (wc < w) canvas.fillRect(4 + wc, y, w - wc, 6, COL_MAGENTA);
  char buf[28];
  snprintf(buf, sizeof(buf), "C %.0f%%  A %.0f%%", 100.f * pc / tot, 100.f * pa / tot);
  gfxText(canvas, 4, y - 10, buf, COL_LIGHTGREY, COL_BLACK, 1);
}

static void drawMain() {
  drawStatusBar();
  const bool charging = snap.ia_ma > Session::kLoadMa || snap.ic_ma > Session::kLoadMa;
  const bool flash = millis() < protoFlashUntil;
  const char* proto = SW3518::protocolName(snap.protocol);

  // Header row under status bar
  gfxText(canvas, 4, kYHdr, charging ? "LIVE" : "IDLE", charging ? COL_GREEN : COL_LIGHTGREY,
          COL_BLACK, 1);
  if (flash) canvas.fillRect(kW / 2 - 40, kYHdr, 80, 10, COL_YELLOW);
  gfxText(canvas, kW / 2, kYHdr, proto, flash ? COL_BLACK : COL_YELLOW,
          flash ? COL_YELLOW : COL_BLACK, 1, true);

  char buf[40];
  snprintf(buf, sizeof(buf), "%.1fW", snap.power_total_w);
  gfxText(canvas, kW / 2, kYWatts, buf, COL_WHITE, COL_BLACK, 3, true);

  snprintf(buf, sizeof(buf), "Vin%.1f", snap.vin_mv / 1000.0f);
  gfxText(canvas, 4, kYMainVin, buf, COL_LIGHTGREY, COL_BLACK, 1);
  snprintf(buf, sizeof(buf), "Vout%.2f", snap.vout_mv / 1000.0f);
  gfxText(canvas, 66, kYMainVin, buf, COL_LIGHTGREY, COL_BLACK, 1);

  gfxText(canvas, 4, kYMainAmps, "C", COL_YELLOW, COL_BLACK, 1);
  snprintf(buf, sizeof(buf), "%.2fA", snap.ic_ma / 1000.0f);
  gfxText(canvas, 14, kYMainAmps, buf, COL_WHITE, COL_BLACK, 1);
  gfxText(canvas, 66, kYMainAmps, "A", COL_MAGENTA, COL_BLACK, 1);
  snprintf(buf, sizeof(buf), "%.2fA", snap.ia_ma / 1000.0f);
  gfxText(canvas, 76, kYMainAmps, buf, COL_WHITE, COL_BLACK, 1);

  drawLoadShareBar(kYShareBar);

  if (session.hasData()) {
    char dur[16];
    formatDuration(session.chargedMs, dur, sizeof(dur));
    snprintf(buf, sizeof(buf), "%s %.2fWh pk%.0f", dur, session.mwh / 1000.0f, session.peakW);
    gfxText(canvas, 4, kYMainSes, buf, COL_LIGHTGREY, COL_BLACK, 1);
  } else {
    gfxText(canvas, 4, kYMainSes, "A=pg B=ses holdB=clr", COL_DIM, COL_BLACK, 1);
  }

  drawSparkline(canvas, 4, kYMainSpark, 56, kMainSparkH, session.histC, COL_YELLOW,
                session.histCount);
  drawSparkline(canvas, 68, kYMainSpark, 56, kMainSparkH, session.histA, COL_MAGENTA,
                session.histCount);
}

static void drawPort(bool usbC) {
  drawStatusBar();
  const uint16_t accent = usbC ? COL_YELLOW : COL_MAGENTA;
  const float amps = (usbC ? snap.ic_ma : snap.ia_ma) / 1000.0f;
  const float watts = usbC ? snap.power_c_w : snap.power_a_w;
  const PortStats& port = usbC ? session.portC : session.portA;
  const float peakA = port.peakA;
  const float peakW = port.peakW;

  gfxText(canvas, 4, kYHdr, usbC ? "USB-C" : "USB-A", accent, COL_BLACK, 1);
  gfxText(canvas, kW / 2, kYHdr, SW3518::protocolName(snap.protocol), COL_LIGHTGREY, COL_BLACK, 1,
          true);

  char buf[32];
  snprintf(buf, sizeof(buf), "%.2fW", watts);
  gfxText(canvas, kW / 2, kYWatts, buf, COL_WHITE, COL_BLACK, 3, true);

  snprintf(buf, sizeof(buf), "%.2fV", snap.vout_mv / 1000.0f);
  gfxText(canvas, 4, kYPortVA, buf, COL_LIGHTGREY, COL_BLACK, 1);
  snprintf(buf, sizeof(buf), "%.2fA", amps);
  gfxText(canvas, 68, kYPortVA, buf, COL_WHITE, COL_BLACK, 1);

  snprintf(buf, sizeof(buf), "pk %.2fA %.1fW", peakA, peakW);
  gfxText(canvas, 4, kYPortPk, buf, COL_LIGHTGREY, COL_BLACK, 1);

  char dur[16];
  formatDuration(session.chargedMs, dur, sizeof(dur));
  snprintf(buf, sizeof(buf), "chg %s", dur);
  gfxText(canvas, 4, kYPortChg, buf, COL_DARKGREY, COL_BLACK, 1);

  drawSparkline(canvas, 4, kYPortSpark, kW - 8, kPortSparkH, usbC ? session.histC : session.histA,
                accent, session.histCount);
}

static void drawSession() {
  drawStatusBar();
  gfxText(canvas, 4, kYHdr, "SESSION", COL_CYAN, COL_BLACK, 1);

  char buf[40], dur[16];
  if (session.hasData()) {
    formatDuration(session.chargedMs, dur, sizeof(dur));
  } else {
    snprintf(dur, sizeof(dur), "--");
  }
  gfxText(canvas, kW - 4, kYHdr, dur, COL_WHITE, COL_BLACK, 1, false, true);

  const float wh = session.mwh / 1000.0f;
  gfxText(canvas, 4, kYSesGrid, "PEAK", COL_DARKGREY, COL_BLACK, 1);
  gfxText(canvas, 46, kYSesGrid, "AVG", COL_DARKGREY, COL_BLACK, 1);
  gfxText(canvas, 88, kYSesGrid, "Wh", COL_DARKGREY, COL_BLACK, 1);

  snprintf(buf, sizeof(buf), "%.1f", session.peakW);
  gfxText(canvas, 4, kYSesVals, buf, COL_WHITE, COL_BLACK, 2);
  snprintf(buf, sizeof(buf), "%.1f", session.avgW());
  gfxText(canvas, 46, kYSesVals, buf, COL_WHITE, COL_BLACK, 2);
  snprintf(buf, sizeof(buf), "%.2f", wh);
  gfxText(canvas, 88, kYSesVals, buf, COL_ORANGE, COL_BLACK, 1);

  snprintf(buf, sizeof(buf), "Vpk %.2f", session.peakVoutMv / 1000.0f);
  gfxText(canvas, 4, kYSesVpk, buf, COL_LIGHTGREY, COL_BLACK, 1);

  snprintf(buf, sizeof(buf), "C pk %.1fW @%.2fA", session.portC.peakW, session.portC.ampsAtPeakW);
  gfxText(canvas, 4, kYSesCLbl, buf, COL_YELLOW, COL_BLACK, 1);
  drawSparkline(canvas, 4, kYSesCSpark, kW - 8, kSesSparkH, session.histC, COL_YELLOW,
                session.histCount);

  snprintf(buf, sizeof(buf), "A pk %.1fW @%.2fA", session.portA.peakW, session.portA.ampsAtPeakW);
  gfxText(canvas, 4, kYSesALbl, buf, COL_MAGENTA, COL_BLACK, 1);
  drawSparkline(canvas, 4, kYSesASpark, kW - 8, kSesSparkH, session.histA, COL_MAGENTA,
                session.histCount);
}

static void setPage(Page p) {
  if (p == page) return;
  page = p;
  hapticPulse(25, 160);
  touchActivity();
}

static void nextPage() {
  uint8_t i = (uint8_t)page;
  i = (i + 1) % (uint8_t)Page::Count;
  setPage(static_cast<Page>(i));
}

static void prevPage() {
  uint8_t i = (uint8_t)page;
  i = (i == 0) ? ((uint8_t)Page::Count - 1) : (i - 1);
  setPage(static_cast<Page>(i));
}

static void drawFrame() {
  canvas.fillScreen(COL_BLACK);
  switch (page) {
    case Page::Main: drawMain(); break;
    case Page::UsbC: drawPort(true); break;
    case Page::UsbA: drawPort(false); break;
    case Page::Session: drawSession(); break;
    default: drawMain(); break;
  }
#if !(defined(WOKWI_SIM) && WOKWI_SIM)
  tft.drawRGBBitmap(0, 0, canvas.getBuffer(), kW, kH);
#endif
}

// --- simple button grammar (no OneButton dep) ---
struct Btn {
  int pin;
  bool stable = true;  // HIGH = released (pullup)
  bool rawPrev = true;
  uint32_t lastChange = 0;
  uint32_t pressStart = 0;
  bool longFired = false;
};

static Btn btnA{PIN_BTN_A};
static Btn btnB{PIN_BTN_B};

static void serviceBtn(Btn& b, void (*onShort)(), void (*onLong)()) {
  const bool raw = digitalRead(b.pin);  // HIGH = up
  const uint32_t now = millis();
  if (raw != b.rawPrev) {
    b.rawPrev = raw;
    b.lastChange = now;
  }
  if ((now - b.lastChange) < kDebounceMs) {
    // still debounce edge, but allow long-press while held
  } else if (raw != b.stable) {
    b.stable = raw;
    if (!b.stable) {
      b.pressStart = now;
      b.longFired = false;
      touchActivity();
    } else {
      if (!b.longFired && (now - b.pressStart) >= kDebounceMs) {
        if (onShort) onShort();
      }
    }
  }
  if (!b.stable && !b.longFired && (now - b.pressStart) >= kLongPressMs) {
    b.longFired = true;
    if (onLong) onLong();
  }
}

static void onAShort() { nextPage(); }
static void onALong() { hapticPulse(120, 255); }
static void onBShort() {
  // jump Session if not there; else prev
  if (page != Page::Session) setPage(Page::Session);
  else prevPage();
}
static void onBLong() {
  clearSession();
  setPage(Page::Main);
}

static void initDisplay() {
  pinMode(PIN_TFT_BL, OUTPUT);
  setBacklight(kBlFull);

#if defined(WOKWI_SIM) && WOKWI_SIM
  // Soft-SPI path: do not call SPI.begin() (would claim pins / fight bitbang).
  tft.initR(ST7735_INIT_TAB);
  tft.setRotation(0);
  // High-contrast prove-alive (custom chip framebuffer)
  tft.fillScreen(ST77XX_RED);
  delay(200);
  tft.fillScreen(ST77XX_GREEN);
  delay(200);
  tft.fillScreen(COL_BLACK);
#else
  // SPI0 remapped to front-edge GP2/GP3 (not the back-pad defaults 18/19)
  SPI.setSCK(PIN_TFT_SCK);
  SPI.setTX(PIN_TFT_MOSI);
  SPI.begin(true);

  tft.initR(ST7735_INIT_TAB);
  tft.setRotation(0);  // 128 x 128
  tft.fillScreen(COL_BLACK);
#endif
}

void setup() {
  Serial.begin(115200);
  delay(200);
#if defined(CHARGER_PICOW)
  Serial.println("sw3518-picow");
#else
  Serial.println("sw3518-rp2350-zero");
#endif

  pinMode(PIN_BTN_A, INPUT_PULLUP);
  pinMode(PIN_BTN_B, INPUT_PULLUP);
  pinMode(PIN_HAPTIC, OUTPUT);
  digitalWrite(PIN_HAPTIC, LOW);
  analogWrite(PIN_HAPTIC, 0);

  initDisplay();
  canvas.fillScreen(COL_BLACK);
#if defined(CHARGER_PICOW)
  gfxText(canvas, kW / 2, kH / 2 - 6, "SW3518 PicoW", COL_CYAN, COL_BLACK, 1, true);
#else
  gfxText(canvas, kW / 2, kH / 2 - 6, "SW3518 Zero", COL_CYAN, COL_BLACK, 1, true);
#endif
#if !(defined(WOKWI_SIM) && WOKWI_SIM)
  tft.drawRGBBitmap(0, 0, canvas.getBuffer(), kW, kH);
#endif

  netSetup();  // Pico W: CYW43 (Wi-Fi + LED_BUILTIN) before status LED
  statusLedBegin();
  statusLedNoteTft(true);  // SPI TFT has no MISO — cannot prove the panel is attached
  charger.begin(PIN_I2C_SDA, PIN_I2C_SCL, 100000);
  Serial.printf("SW3518 %s @0x%02X SDA=%d SCL=%d\n", charger.present() ? "OK" : "MISSING",
                (unsigned)SW3518::kAddr, PIN_I2C_SDA, PIN_I2C_SCL);

  lastActivityMs = millis();
  hapticPulse(30, 180);
}

void loop() {
  const uint32_t now = millis();
  hapticService();
  netTick();

  serviceBtn(btnA, onAShort, onALong);
  serviceBtn(btnB, onBShort, onBLong);

  static uint32_t lastProbeMs = 0;
  if (now - lastUiMs >= kUiMsEffective) {
    lastUiMs = now;
    if (charger.readSnapshot(snap)) {
      if (snap.protocol != lastProtocol) {
        lastProtocol = snap.protocol;
        protoFlashUntil = now + 2000;
        hapticPulse(35, 180);
      }
      const ChargeSample sample = snap.sample();
      session.onTick(now, &sample, Link::Ok);
      if (now - lastHistPushMs >= session.histPeriodMs) {
        lastHistPushMs = now;
        session.pushHistory(snap.power_c_w, snap.power_a_w);
      }
    } else {
      snap = SW3518::Snapshot{};
      lastProtocol = SW3518::Protocol::None;
      if (now - lastProbeMs >= 1000) {
        lastProbeMs = now;
        if (charger.probe()) charger.rearm();
      }
      session.onTick(now, nullptr, Link::Lost);
    }
    drawFrame();
    uint8_t faults = STATUS_OK;
    if (!charger.present()) faults |= STATUS_NO_SW3518;
    statusLedShow(faults, nightDim);
    static uint32_t lastMqttMs = 0;
    if (now - lastMqttMs >= 2000) {
      lastMqttMs = now;
      netPublish(snap, session, charger.present());
    }
  }

  // night dim
  if (!nightDim && (now - lastActivityMs) > kNightIdleMs) {
    nightDim = true;
    setBacklight(kBlDim);
  }
}

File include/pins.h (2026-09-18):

#pragma once

// Default pin map — Waveshare RP2350-Zero + 1.4" 128x128 SPI TFT + SW3518 + buttons + haptic.
// Change here; rebuild. Documented again in README.

#if defined(CHARGER_PICOW)
// Raspberry Pi Pico W — every GPIO is on the 40-pin edge. Use SPI0 defaults
// (GP16–21 sit on the right rail). No onboard WS2812; status is LED_BUILTIN.
static const int PIN_TFT_SCK  = 18;
static const int PIN_TFT_MOSI = 19;
static const int PIN_TFT_CS   = 17;
// No DC/A0/RS pad: Adafruit 3-wire (9-bit) SPI. If your glass has A0 or RS, that IS DC — set to 16.
static const int PIN_TFT_DC   = -1;
static const int PIN_TFT_RST  = 20;
static const int PIN_TFT_BL   = 21;
#else
// Waveshare RP2350-Zero — TFT on *front* castellated edge (USB-C at top).
// SPI0 remapped off back-pad defaults (GP18/19) onto GP2/GP3.
static const int PIN_TFT_SCK  = 2;
static const int PIN_TFT_MOSI = 3;
static const int PIN_TFT_CS   = 1;
static const int PIN_TFT_DC   = 15;  // GP16 is the onboard WS2812
static const int PIN_TFT_RST  = 8;
static const int PIN_TFT_BL   = 14;
static const int PIN_WS2812   = 16;  // onboard WS2812B
#endif

// 128x128 panels need the 144 tab (sets 128 height + col/row start).
// Do not use INITR_BLACKTAB / INITR_GREENTAB here — those are 128x160 1.8".
// If the image is shifted a few pixels, try INITR_HALLOWING (also 128x128).
#ifndef ST7735_INIT_TAB
#define ST7735_INIT_TAB INITR_144GREENTAB
#endif

// --- SW3518 I2C ---
// GP4/GP5 are I2C0 (Wire) on RP2350. (User shorthand "I2C1" = this bus.)
static const int PIN_I2C_SDA = 4;
static const int PIN_I2C_SCL = 5;
static const uint8_t SW3518_I2C_ADDR = 0x3C;

// --- Momentary buttons on case LID beside screen (active LOW, INPUT_PULLUP) ---
static const int PIN_BTN_A = 6;  // short = next page; long = haptic test
static const int PIN_BTN_B = 7;  // short = prev / jump Session; long = clear session
// Optional 3rd button (Mode) — GP8 is TFT RST; use GP10+ if needed.
// static const int PIN_BTN_MODE = 10;

// --- Haptic motor via N-FET gate (active HIGH) ---
static const int PIN_HAPTIC = 9;

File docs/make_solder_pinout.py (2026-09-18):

#!/usr/bin/env python3
"""Rough soldering pinout from include/pins.h + Waveshare RP2350-Zero wiki pinout."""
from pathlib import Path
from PIL import Image, ImageDraw, ImageFont

W, H = 1680, 1030
BG, CARD, INK, MUTED = (18, 18, 20), (32, 32, 36), (240, 240, 235), (140, 140, 145)
LINE = (70, 70, 76)

C = {
    "pwr": (220, 70, 70),
    "gnd": (90, 90, 95),
    "tft": (255, 160, 50),
    "i2c": (80, 210, 220),
    "btn": (240, 210, 70),
    "hap": (220, 90, 200),
    "led": (80, 200, 90),
    "adc": (120, 180, 255),
    "free": (55, 55, 60),
}

FRONT_L = [
    ("5V", "VIN", "pwr"),
    ("GND", "", "gnd"),
    ("3V3", "", "pwr"),
    ("29", "", "free"),
    ("28", "", "free"),
    ("27", "", "free"),
    ("26", "", "free"),
    ("15", "TFT DC", "tft"),
    ("14", "TFT BL", "tft"),
]
FRONT_R = [
    ("0", "", "free"),
    ("1", "TFT CS", "tft"),
    ("2", "TFT SCK", "tft"),
    ("3", "TFT MOSI", "tft"),
    ("4", "SW3518 SDA", "i2c"),
    ("5", "SW3518 SCL  (silk SCK)", "i2c"),
    ("6", "BTN A", "btn"),
    ("7", "BTN B", "btn"),
    ("8", "TFT RST", "tft"),
    ("9", "HAPTIC FET gate", "hap"),
    ("10", "", "free"),
    ("11", "", "free"),
    ("12", "", "free"),
    ("13", "", "free"),
]
BACK_R = [
    ("25", "", "free"),
    ("24", "", "free"),
    ("23", "", "free"),
    ("22", "", "free"),
    ("21", "", "free"),
    ("20", "", "free"),
    ("19", "", "free"),
    ("18", "", "free"),
    ("17", "", "free"),
    ("GND", "", "gnd"),
]


def font(px, bold=False):
    name = "DejaVuSans-Bold.ttf" if bold else "DejaVuSans.ttf"
    try:
        return ImageFont.truetype(f"/usr/share/fonts/truetype/dejavu/{name}", px)
    except OSError:
        return ImageFont.load_default()


def rounded(d, box, fill, r=10):
    d.rounded_rectangle(box, radius=r, fill=fill)


def pad(d, xy, label, role, used, fonts):
    x, y = xy
    col = C[role]
    d.ellipse((x, y, x + 16, y + 16), fill=col, outline=(0, 0, 0))
    tag = label if label in ("5V", "GND", "3V3") else f"GP{label}" if label.isdigit() else label
    text = f"{tag}  {used}" if used else tag
    d.text((x + 22, y), text, font=fonts["sm"], fill=INK if used else MUTED)


def board(d, x, y, title, left, right, fonts, usb=True):
    rounded(d, (x, y, x + 220, y + 540), (25, 55, 130), 16)
    d.rounded_rectangle((x + 70, y - 8, x + 150, y + 28), radius=6, fill=(40, 40, 45), outline=(180, 180, 180))
    d.text((x + 88, y + 4), "USB-C", font=fonts["tiny"], fill=INK)
    d.text((x + 48, y + 36), title, font=fonts["sm"], fill=(200, 220, 255))
    if usb:
        d.rectangle((x + 40, y + 58, x + 78, y + 78), fill=(60, 60, 70))
        d.text((x + 44, y + 62), "BOOT", font=fonts["tiny"], fill=MUTED)
        d.rectangle((x + 142, y + 58, x + 180, y + 78), fill=(60, 60, 70))
        d.text((x + 148, y + 62), "RUN", font=fonts["tiny"], fill=MUTED)
    ly, ry = y + 90, y + 90
    if left:
        for lab, used, role in left:
            pad(d, (x - 130, ly), lab, role, used, fonts)
            d.line((x - 4, ly + 9, x + 8, ly + 9), fill=C[role], width=2)
            ly += 34
    if right:
        for lab, used, role in right:
            pad(d, (x + 228, ry), lab, role, used, fonts)
            d.line((x + 212, ry + 9, x + 226, ry + 9), fill=C[role], width=2)
            ry += 28 if len(right) > 10 else 34


def card(d, x, y, w, h, title, lines, color, fonts):
    rounded(d, (x, y, x + w, y + h), CARD, 12)
    d.rectangle((x, y, x + 8, y + h), fill=color)
    d.text((x + 18, y + 10), title, font=fonts["h"], fill=color)
    yy = y + 40
    for line in lines:
        d.text((x + 18, yy), line, font=fonts["sm"], fill=INK)
        yy += 22


def main():
    im = Image.new("RGB", (W, H), BG)
    d = ImageDraw.Draw(im)
    fonts = {
        "h": font(22, True),
        "sm": font(14, True),
        "tiny": font(11),
        "title": font(28, True),
    }
    d.text((40, 24), "sw3518-rp2350-zero  —  solder pinout (rough)", font=fonts["title"], fill=INK)
    d.text((40, 58), "From include/pins.h  ·  Zero pin order = Waveshare wiki  ·  USB-C at TOP", font=fonts["sm"], fill=MUTED)

    board(d, 190, 95, "FRONT  (USB / buttons)", FRONT_L, FRONT_R, fonts, usb=True)
    board(d, 1020, 95, "BACK  (chip / WS2812)", None, BACK_R, fonts, usb=True)
    rounded(d, (480, 600, 900, 658), (30, 50, 32), 8)
    d.text((494, 610), "WS2812 onboard GP16 DIN", font=fonts["sm"], fill=C["led"])
    d.text((494, 632), "do not solder TFT DC here", font=fonts["tiny"], fill=C["led"])

    card(
        d,
        40,
        680,
        370,
        320,
        "1.4in ST7735 TFT",
        [
            "VCC  ->  3V3",
            "GND  ->  GND",
            "SCK  ->  GP2    FRONT",
            "MOSI ->  GP3    FRONT",
            "CS   ->  GP1    FRONT",
            "DC   ->  GP15   FRONT  (not 16)",
            "RST  ->  GP8    FRONT",
            "BL   ->  GP14   FRONT",
            "No MISO. All front edge.",
        ],
        C["tft"],
        fonts,
    )
    card(
        d,
        430,
        680,
        370,
        320,
        "SW3518 I2C  0x3C",
        [
            "SDA  ->  GP4    FRONT",
            "SCL  ->  GP5    FRONT",
            "GND  ->  GND",
            "",
            "Module silk SCK = I2C SCL",
            "not SPI clock.",
            "Share GND with the Zero.",
            "Do not feed charger VBUS",
            "into 3V3.",
        ],
        C["i2c"],
        fonts,
    )
    card(
        d,
        820,
        680,
        360,
        320,
        "Buttons A / B",
        [
            "A  GP6  -> switch -> GND",
            "B  GP7  -> switch -> GND",
            "",
            "INPUT_PULLUP, active LOW",
            "Short A = next page",
            "Short B = session",
            "Hold B = clear session",
        ],
        C["btn"],
        fonts,
    )
    card(
        d,
        1200,
        680,
        360,
        320,
        "Haptic  N-FET",
        [
            "GP9 -> ~100R -> FET gate",
            "FET source -> GND",
            "FET drain  -> motor -",
            "motor +    -> 3V3 or 5V",
            "diode across motor",
            "  (cathode to +)",
            "Do not drive motor",
            "from a GPIO.",
        ],
        C["hap"],
        fonts,
    )

    out = Path(__file__).resolve().parent / "wiring-solder-guide.png"
    im.save(out, "PNG")
    print("wrote", out)


if __name__ == "__main__":
    main()

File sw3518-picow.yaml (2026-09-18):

# SW3518 charger meter — Raspberry Pi Pico W + ESPHome (native HA API).
# Pins match env:picow / docs/wiring-solder-guide-picow.png
#
#   Open this REPO ROOT in VS Code (folder that contains platformio.ini).
#   cp secrets.yaml.example secrets.yaml
#   esphome run sw3518-picow.yaml
#
# First flash: hold Pico BOOT, plug USB, then esphome run (UF2). Later: OTA.

esphome:
  name: sw3518-picow
  friendly_name: SW3518 Pico W

rp2040:
  board: rpipicow

logger:
api:
ota:
  platform: esphome

wifi:
  ssid: !secret wifi_ssid
  password: !secret wifi_password

external_components:
  # Folder `components/sw3518` next to this yaml (ESPHome's required layout).
  - source: components
    components: [sw3518]

i2c:
  sda: GPIO4
  scl: GPIO5
  scan: true
  frequency: 100kHz
  id: i2c_bus

spi:
  clk_pin: GPIO18
  mosi_pin: GPIO19
  # no MISO — ST7735 is write-only

sw3518:
  id: charger
  address: 0x3C
  update_interval: 1s

sensor:
  - platform: sw3518
    sw3518_id: charger
    vin:
      name: Input voltage
      id: vin
    vout:
      name: Output voltage
      id: vout
    current_c:
      name: USB-C current
      id: ic
    current_a:
      name: USB-A current
      id: ia
    power:
      name: Total power
      id: power
    power_c:
      name: USB-C power
      id: power_c
    power_a:
      name: USB-A power
      id: power_a
  - platform: integration
    name: Session energy
    id: session_wh
    sensor: power
    time_unit: h
    restore: false
    unit_of_measurement: Wh
    device_class: energy
    state_class: measurement

text_sensor:
  - platform: sw3518
    sw3518_id: charger
    protocol:
      name: Charge protocol
      id: protocol

binary_sensor:
  - platform: sw3518
    sw3518_id: charger
    linked:
      name: SW3518 linked
      id: linked
    charging:
      name: Charging
      id: charging
  - platform: gpio
    pin:
      number: GPIO6
      inverted: true
      mode:
        input: true
        pullup: true
    id: btn_a
    name: Button A
    internal: true
    on_press:
      then:
        - lambda: |-
            id(ui_page) = (id(ui_page) + 1) % 2;
        - output.turn_on: haptic_out
        - delay: 40ms
        - output.turn_off: haptic_out
        - component.update: tft
  - platform: gpio
    pin:
      number: GPIO7
      inverted: true
      mode:
        input: true
        pullup: true
    id: btn_b
    name: Button B
    internal: true
    on_multi_click:
      - timing:
          - ON for at most 0.5s
        then:
          - lambda: "id(ui_page) = 1;"
          - component.update: tft
      - timing:
          - ON for at least 0.8s
        then:
          - sensor.integration.reset: session_wh
          - output.turn_on: haptic_out
          - delay: 80ms
          - output.turn_off: haptic_out

output:
  - platform: rp2040_pwm
    pin: GPIO21
    id: tft_bl
    frequency: 1000Hz
  - platform: gpio
    pin: GPIO9
    id: haptic_out

light:
  - platform: monochromatic
    output: tft_bl
    name: TFT backlight
    id: backlight
    restore_mode: ALWAYS_ON
    default_transition_length: 0s

globals:
  - id: ui_page
    type: int
    restore_value: false
    initial_value: "0"

font:
  - file: "gfonts://Roboto"
    id: font12
    size: 12
  - file: "gfonts://Roboto"
    id: font22
    size: 22

color:
  - id: col_white
    hex: FFFFFF
  - id: col_grey
    hex: AAAAAA
  - id: col_cyan
    hex: 00FFFF
  - id: col_yellow
    hex: FFFF00
  - id: col_orange
    hex: FF8000
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

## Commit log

2026-09-09 Initial portable SW3518 meter for Waveshare RP2350-Zero.
    ST7735 128x160 UI (Main/C/A/Session), I2C driver adapted from GEEK,
    buttons + haptic, PlatformIO earlephilhower core. No Wi-Fi/radio.
2026-09-09 Tune 128x160 UI density and add parametric pocket case STLs.
    Polish Main/Port/Session layouts for the portrait panel, and add a
    printable Zero+TFT+SW3518 shell under case/ with friction lid.
    [pocket_bottom.stl, pocket_lid.stl, pocket_preview_exploded.stl]
2026-09-09 Retune pocket case for barrel-jack stacked SW3518S
    Match user's DC-barrel + USB-A/C module (~60x22x14 bay), add side
    barrel cutouts, and document SCK silkscreen as I2C SCL.
    [pocket_bottom.stl, pocket_lid.stl, pocket_preview_exploded.stl]
2026-09-09 Fix SW3518 pocket: barrel on case end, USB on long side
    Replace unusable side pinholes with a flared DC mouth at +X and a
    generous stacked A/C window on +Y so plugs actually fit.
    [pocket_bottom.stl, pocket_lid.stl, pocket_preview_exploded.stl]
2026-09-09 Rebuild pocket case with SW3518 flush on both ends
    Charger module is the length spine: barrel and stacked USB sit flush
    on opposite case ends; TFT and RP2350-Zero stack on the upper deck.
    [pocket_bottom.stl, pocket_lid.stl, pocket_preview_exploded.stl]
2026-09-09 Fix floating rail bars in pocket bottom STL
    Fuse seat/deck ledges into the side walls so the mesh is a single
    manifold body (v4.1).
    [pocket_bottom.stl, pocket_preview_exploded.stl]
2026-09-09 Move case buttons to lid beside screen
    Remove long-side tact holes that cut the walls; add A/B openings on
    the lid next to the TFT window with inner countersinks for 6x6 switches.
    [pocket_bottom.stl, pocket_lid.stl, pocket_preview_exploded.stl]
2026-09-09 v5 case: explain Zero USB notch, tighten module ports
    Replace chewed corner with a neat mid-side Zero USB-C slot. Snug
    barrel circle + dual-tier A/C mouth, SW mounting bosses, and cap wells.
    [pocket_bottom.stl, pocket_lid.stl, pocket_preview_exploded.stl]
2026-09-09 v5.1: remove corner USB cut and through-wall ledge bars
    Side ledges stay inside the cavity; Zero is flashed with the lid off
    so the long walls stay clean.
    [pocket_bottom.stl, pocket_lid.stl, pocket_preview_exploded.stl]
2026-09-09 Add v6 sandwich case generator (caliper draft)
2026-09-09 Add v6 case meta from calipers
2026-09-09 Add v6 base STL draft
    [v6_base.stl]
2026-09-09 Add v6 mid plate STL draft
    [v6_mid_plate.stl]
2026-09-09 Add v6 lid STL draft
    [v6_lid.stl]
2026-09-09 Add v6 exploded preview STL
    [v6_preview_exploded.stl]
2026-09-09 v6: barrel H=11, add 7x7x7 IC heatsink keepout well
2026-09-09 v6 meta: barrel 13x11x11 + heatsink keepout
2026-09-09 Regen v6_base with barrel H=11 + heatsink well
    [v6_base.stl]
2026-09-09 Regen v6 preview
    [v6_preview_exploded.stl]
2026-09-09 Regen base: Zero USB notch on +Y
    [v6_base.stl]
2026-09-09 Regen mid: Zero USB notch on +Y
    [v6_mid_plate.stl]
2026-09-09 Regen preview after USB notch fix
    [v6_preview_exploded.stl]
2026-09-09 Regen v6_base from photo layout
    [v6_base.stl]
2026-09-09 Regen v6_mid_plate
    [v6_mid_plate.stl]
2026-09-09 Regen v6_lid port relief swap
    [v6_lid.stl]
2026-09-10 Add v7 STEP rebuild from caliper lock (CadQuery)
    Fresh parametric STEP+STL parts under case/v7_step/ driven only by
    v7_lock.json — base glove gate first, mid with Zero pocket+USB detent,
    lid with aligned holes, TFT tray, optional TPU pad and Zero clip.
    [v7_base.step, v7_base.stl, v7_lid.step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]
2026-09-10 v7 lock: add wiring pinout and flex clearances
    Amend from include/pins.h — I2C/SPI/buttons/haptic, +Y flex channel
    sizing, service slack, silk SCK=SCL note.
2026-09-10 UI: keep normal pages when SW3518 unlinked, show chip icon
    Drop the full-screen missing takeover. Pages stay navigable with
    zeroed values; status bar tints CHG orange and draws a small
    slashed-chip badge until I2C recovers.
    [main.cpp]
2026-09-10 Fix: declare unlink icon helpers before status bar
    [main.cpp]
2026-09-10 Pause session energy on I2C loss; share Session with GEEK
    Replace the local Session struct with the portable onTick(Link)
    model so a dropped SW3518 freezes the clock instead of billing
    the gap. Driver probe() can clear present_; reconnect rearms
    Vin ADC without Wire.begin(). Host tests live in tests/.
    [main.cpp, session.cpp, sw3518.cpp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]
2026-09-12 Add Wokwi Pico sim twin for portable UI
    Wokwi has no RP2350 part yet; pico-wokwi env builds the same pin map
    on RP2040 with WOKWI_SIM fake SW3518 data, diagram.json + ST7735 chip,
    buttons, and haptic LED stand-in.
2026-09-12 Fix Wokwi blank display: ST7735 SCK/MOSI + DC on GP15
    Custom chip uses SCK/MOSI/RST (not SCL/SDA). Pico SPI0 MISO defaults
    to GP16, so the sim twin moves TFT DC to GP15.
    [main.cpp, pins.h]
2026-09-12 Wokwi: soft-SPI ST7735 + red/green prove-alive
    Custom chip often fails with Pico HW SPI in sim; use bitbang SPI under
    WOKWI_SIM and flash red/green on boot so a blank panel is obvious.
    Bump chip-st7735 to 1.0.4.
    [main.cpp]
2026-09-12 Wokwi: draw UI directly to TFT (skip RGB bitmap)
    After red/green prove-alive, full-frame drawRGBBitmap over soft SPI
    never produced a usable UI. Alias canvas to tft under WOKWI_SIM.
    [main.cpp]
2026-09-18 Add onboard WS2812 status LED on GP16.
    Move TFT DC to GP15 so it does not fight the Zero RGB. Blink count: 1 = SW3518 missing, 2 = TFT (reserved, no MISO), 3 = both.
    [main.cpp, pins.h]
2026-09-18 Add a rough Zero-to-parts soldering pinout image.
    Generated from pins.h and the Waveshare RP2350-Zero wiki pad order.
2026-09-18 Add optional GP26 ADC for a millivolt current-sense pad.
    SW3518 port shunts are high-side VBUS in the datasheet; firmware flags Is HI if the pad is not a millivolt node. Meter vs GND before wiring.
2026-09-18 Move TFT SPI onto front-edge GPIOs.
    SPI0 SCK/MOSI remap to GP2/GP3; CS/RST/BL on GP1/8/14. Back pads GP17-21 are free.
2026-09-18 Remove analog I-sense ADC.
    Port current already comes from SW3518 I2C. Drops the analogReadResolution build break on Arduino-Pico.
2026-09-18 Add Pico W env with MQTT Home Assistant discovery.
    Same TFT meter, SPI0 on the 40-pin edge, PubSubClient HA sensors. Zero env unchanged. Solder helper for Pico W.
2026-09-18 Add ESPHome Pico W port with SW3518 I2C component.
    Native HA API, ST7735, buttons, session Wh integrator. Arduino firmware stays; flash one or the other.
2026-09-18 Use 16-bit RGB565 on the Pico W ESPHome ST7735.
    Matches the RP2350 Arduino canvas. Fall back to color_palette 8BIT if RAM is too tight.
    [sw3518-picow.yaml]
2026-09-18 Fix ESPHome sw3518 discovery: GitHub source, AUTOLOAD, hub id.
    VS Code schema still flags unknown sw3518 keys; compile uses the external component from this repo.
    [sw3518-picow.yaml]
2026-09-18 Pico W TFT: 3-wire SPI when the panel has no DC pad.
    PIN_TFT_DC=-1 (Adafruit 9-bit). A0/RS on the glass is still DC to GP16. ESPHome ili9xxx cannot omit DC.
